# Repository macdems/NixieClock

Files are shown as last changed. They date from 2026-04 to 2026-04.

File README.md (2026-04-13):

| Supported Targets | ESP32 | ESP32-C2 | ESP32-C3 | ESP32-C5 | ESP32-C6 | ESP32-C61 | ESP32-H2 | ESP32-H21 | ESP32-H4 | ESP32-P4 | ESP32-S2 | ESP32-S3 | Linux |
| --- | ----- | --- | --- | --- | --- | --- | --- | --- | --- | --- | --- | --- | ----- |

# Hello World Example

Starts a FreeRTOS task to print "Hello World".

(See the README.md file in the upper level 'examples' directory for more information about examples.)

## How to use example

Follow detailed instructions provided specifically for this example.

Select the instructions depending on Espressif chip installed on your development board:

- [ESP32 Getting Started Guide](https://docs.espressif.com/projects/esp-idf/en/stable/get-started/index.html)
- [ESP32-S2 Getting Started Guide](https://docs.espressif.com/projects/esp-idf/en/latest/esp32s2/get-started/index.html)

## Example folder contents

The project **hello_world** contains one source file in C language [hello_world_main.c](main/hello_world_main.c). The file is located in folder [main](main).

ESP-IDF projects are built using CMake. The project build configuration is contained in `CMakeLists.txt` files that provide set of directives and instructions describing the project's source files and targets (executable, library, or both).

Below is short explanation of remaining files in the project folder.

```
├── CMakeLists.txt
├── pytest_hello_world.py      Python script used for automated testing
├── main
│   ├── CMakeLists.txt
│   └── hello_world_main.c
└── README.md                  This is the file you are currently reading
```

For more information on structure and contents of ESP-IDF projects, please refer to Section [Build System](https://docs.espressif.com/projects/esp-idf/en/latest/esp32/api-guides/build-system.html) of the ESP-IDF Programming Guide.

## Troubleshooting

* Program upload failure

    * Hardware connection is not correct: run `idf.py -p PORT monitor`, and reboot your board to see if there are any output logs.
    * The baud rate for downloading is too high: lower your baud rate in the `menuconfig` menu, and try again.

## Technical support and feedback

Please use the following feedback channels:

* For technical queries, go to the [esp32.com](https://esp32.com/) forum
* For a feature request or bug report, create a [GitHub issue](https://github.com/espressif/esp-idf/issues)

We will get back to you as soon as possible.

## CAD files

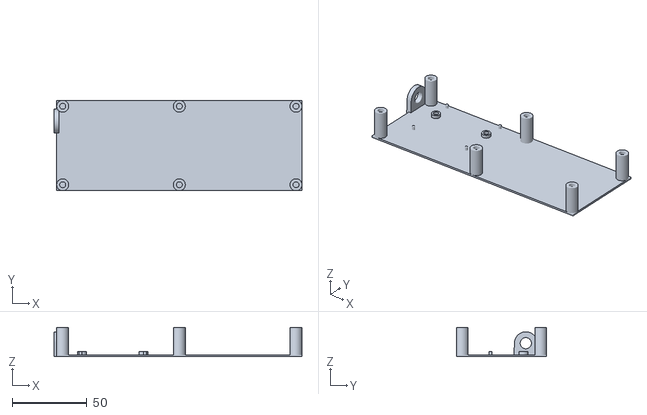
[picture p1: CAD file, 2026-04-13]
NixieClock-Base.stl
165.8 x 60.5 x 19.6

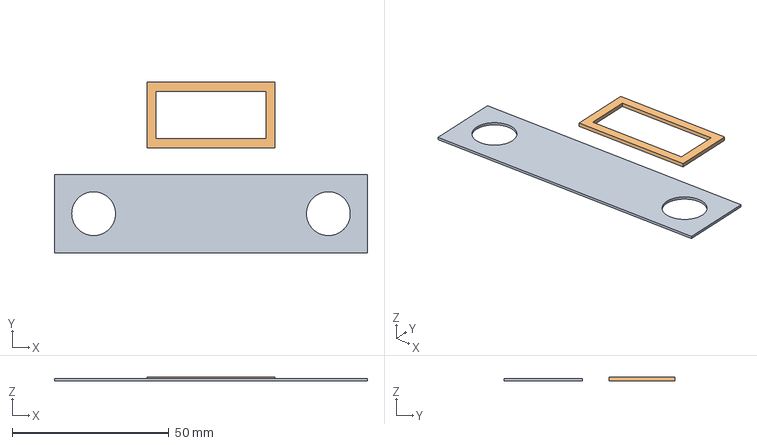
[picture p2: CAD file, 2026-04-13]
Stencil.FCStd
100.0 x 54.5 x 1.20 mm
Pipe
Plate

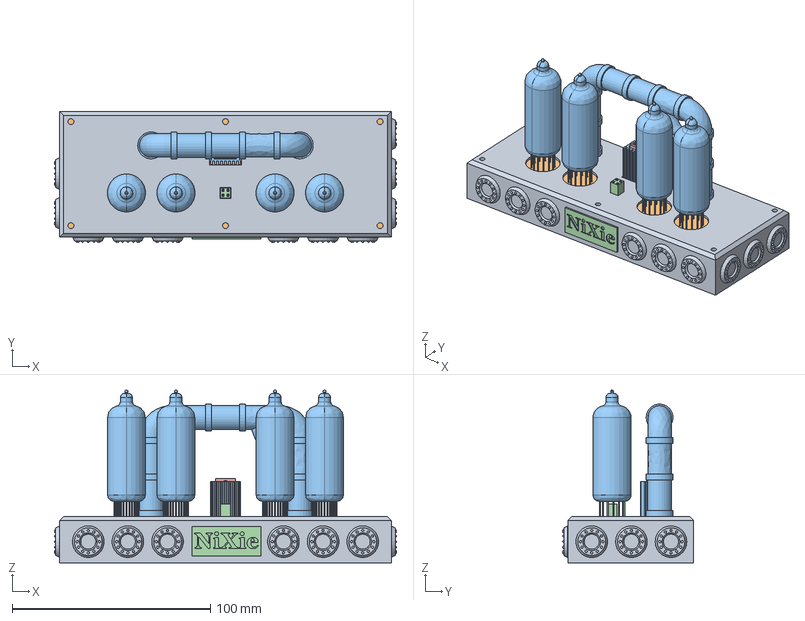
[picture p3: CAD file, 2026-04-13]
NixieClock.FCStd
172.6 x 66.0 x 87.3 mm
Pcb_86ba
HS1_Body_0fe1d42652f7
N5_PinSocket_2x02_P2.54mm_Vertical_931e53dfafea
U8_TO_220_5_Pentawatt_Multiwatt_5_Vertical_StaggeredType1_a8e8bdc4ef04
C2_CP_Radial_D50mm_P250mm_e134c9ee7a58 x 2
U4_DIP-16_W7.62mm_a7dd0eecdeba x 7
R2_R_1206_3216Metric_15a842b50147 x 6
Q2_SOT-23_20dbbeb1f2bc x 9
D6_D_SMA_a3922ec9fb80 x 3
NX-SZP-IN14-v002 x 4
NX-SZP-IN14-v003 x 4
NX-SZP-IN14-v004 x 4
NX-SZP-IN14-v005 x 4
NX-SZP-IN14-v006 x 4
NX-SZP-IN14-v007 x 4
NX-SZP-IN14-v008 x 4
NX-SZP-IN14-v009 x 4
NX-SZP-IN14-v010 x 4
NX-SZP-IN14-v011 x 4
NX-SZP-IN14-v012 x 4
NX-SZP-IN14-v013 x 4
NX-SZP-IN14-v014 x 4
NX-SZP-IN14-v015 x 4
NX-SZP-IN14-v016 x 4
NX-SZP-IN14-v017 x 4
NX-SZP-IN14-v018 x 4
NX-SZP-IN14-v019 x 4
NX-SZP-IN14-v020 x 4
NX-SZP-IN14-v021 x 4
NX-SZP-IN14-v022 x 4
NX-SZP-IN14-v023 x 4
NX-SZP-IN14-v024 x 4
NX-SZP-IN14-v025 x 4
NX-SZP-IN14-v026 x 4
NX-SZP-IN14-v027 x 4
NX-SZP-IN14-v028 x 4
NX-SZP-IN14-v029 x 4
NX-SZP-IN14-v030 x 4
NX-SZP-IN14-v031 x 4
NX-SZP-IN14-v032 x 4
NX-SZP-IN14-v033 x 4
NX-SZP-IN14-v034 x 4
NX-SZP-IN14-v035 x 4
NX-SZP-IN14-v036 x 4
NX-SZP-IN14-v037 x 4
NX-SZP-IN14-v038 x 4
NX-SZP-IN14-v039 x 4
NX-SZP-IN14-v040 x 4
NX-SZP-IN14-v041 x 4
NX-SZP-IN14-v042 x 4
NX-SZP-IN14-v043 x 4
NX-SZP-IN14-v044 x 4
NX-SZP-IN14-v045 x 4
NX-SZP-IN14-v046 x 4
NX-SZP-IN14-v047 x 4
NX-SZP-IN14-v048 x 4
Base
Pipe
Plate

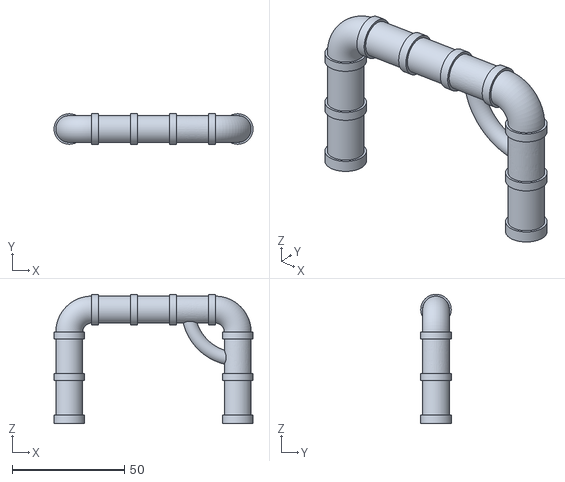
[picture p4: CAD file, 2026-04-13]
NixieClock-Pipe.stl
88.6 x 13.6 x 57.6

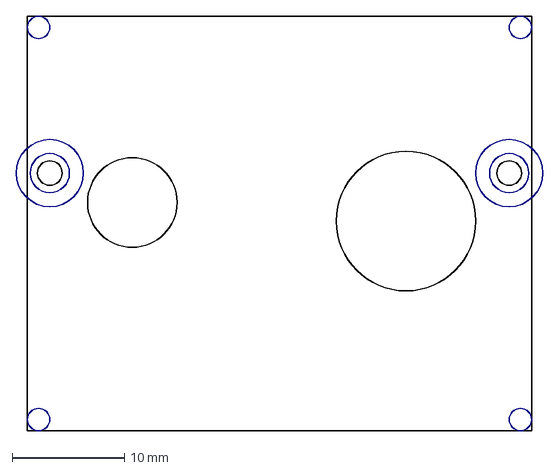
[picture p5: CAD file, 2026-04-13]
power-supply.dxf
47.0 x 37.0 mm

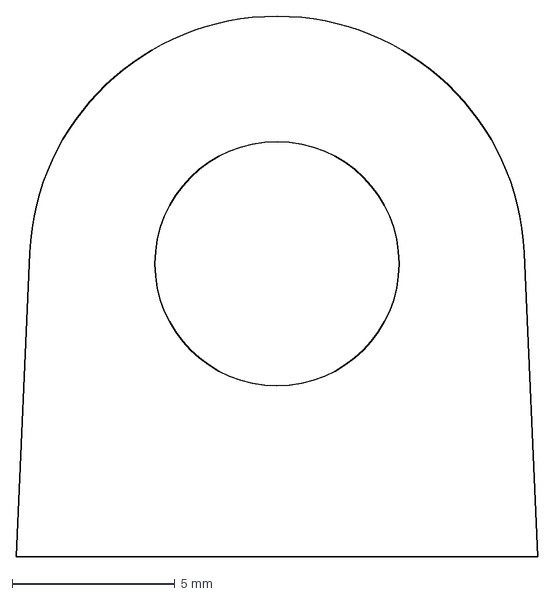
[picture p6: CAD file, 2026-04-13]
socket.dxf
16.0 x 16.6 mm

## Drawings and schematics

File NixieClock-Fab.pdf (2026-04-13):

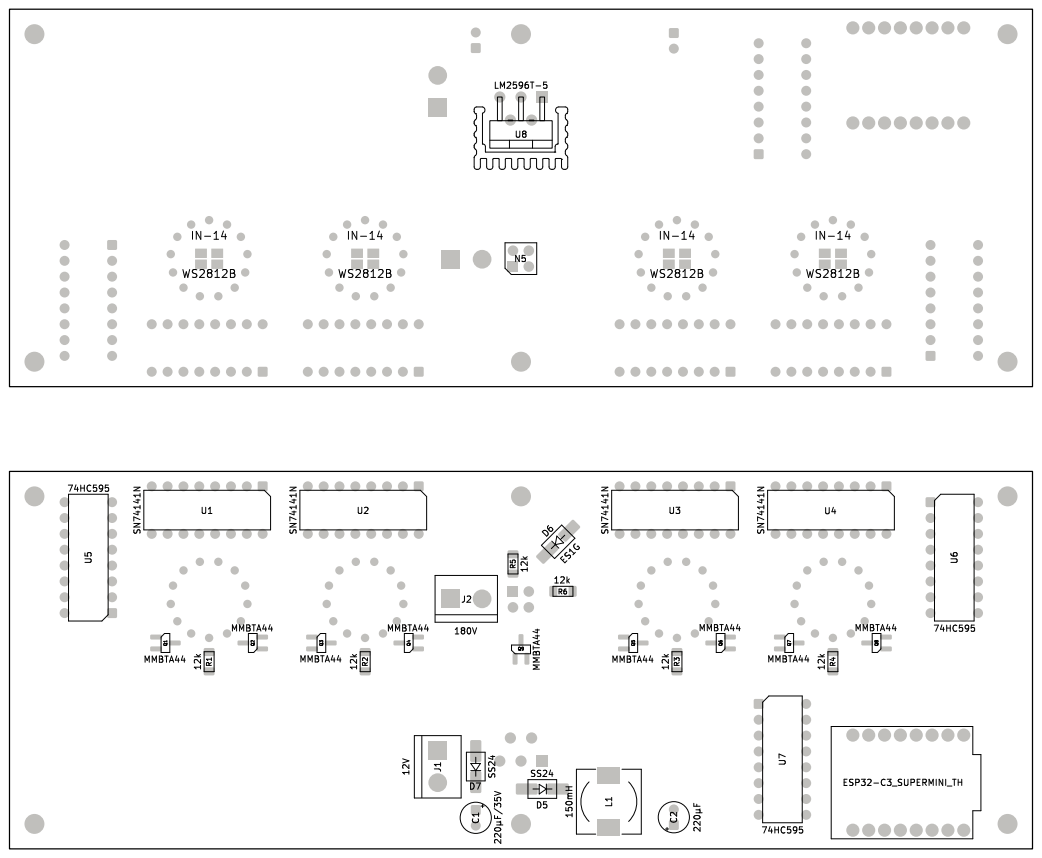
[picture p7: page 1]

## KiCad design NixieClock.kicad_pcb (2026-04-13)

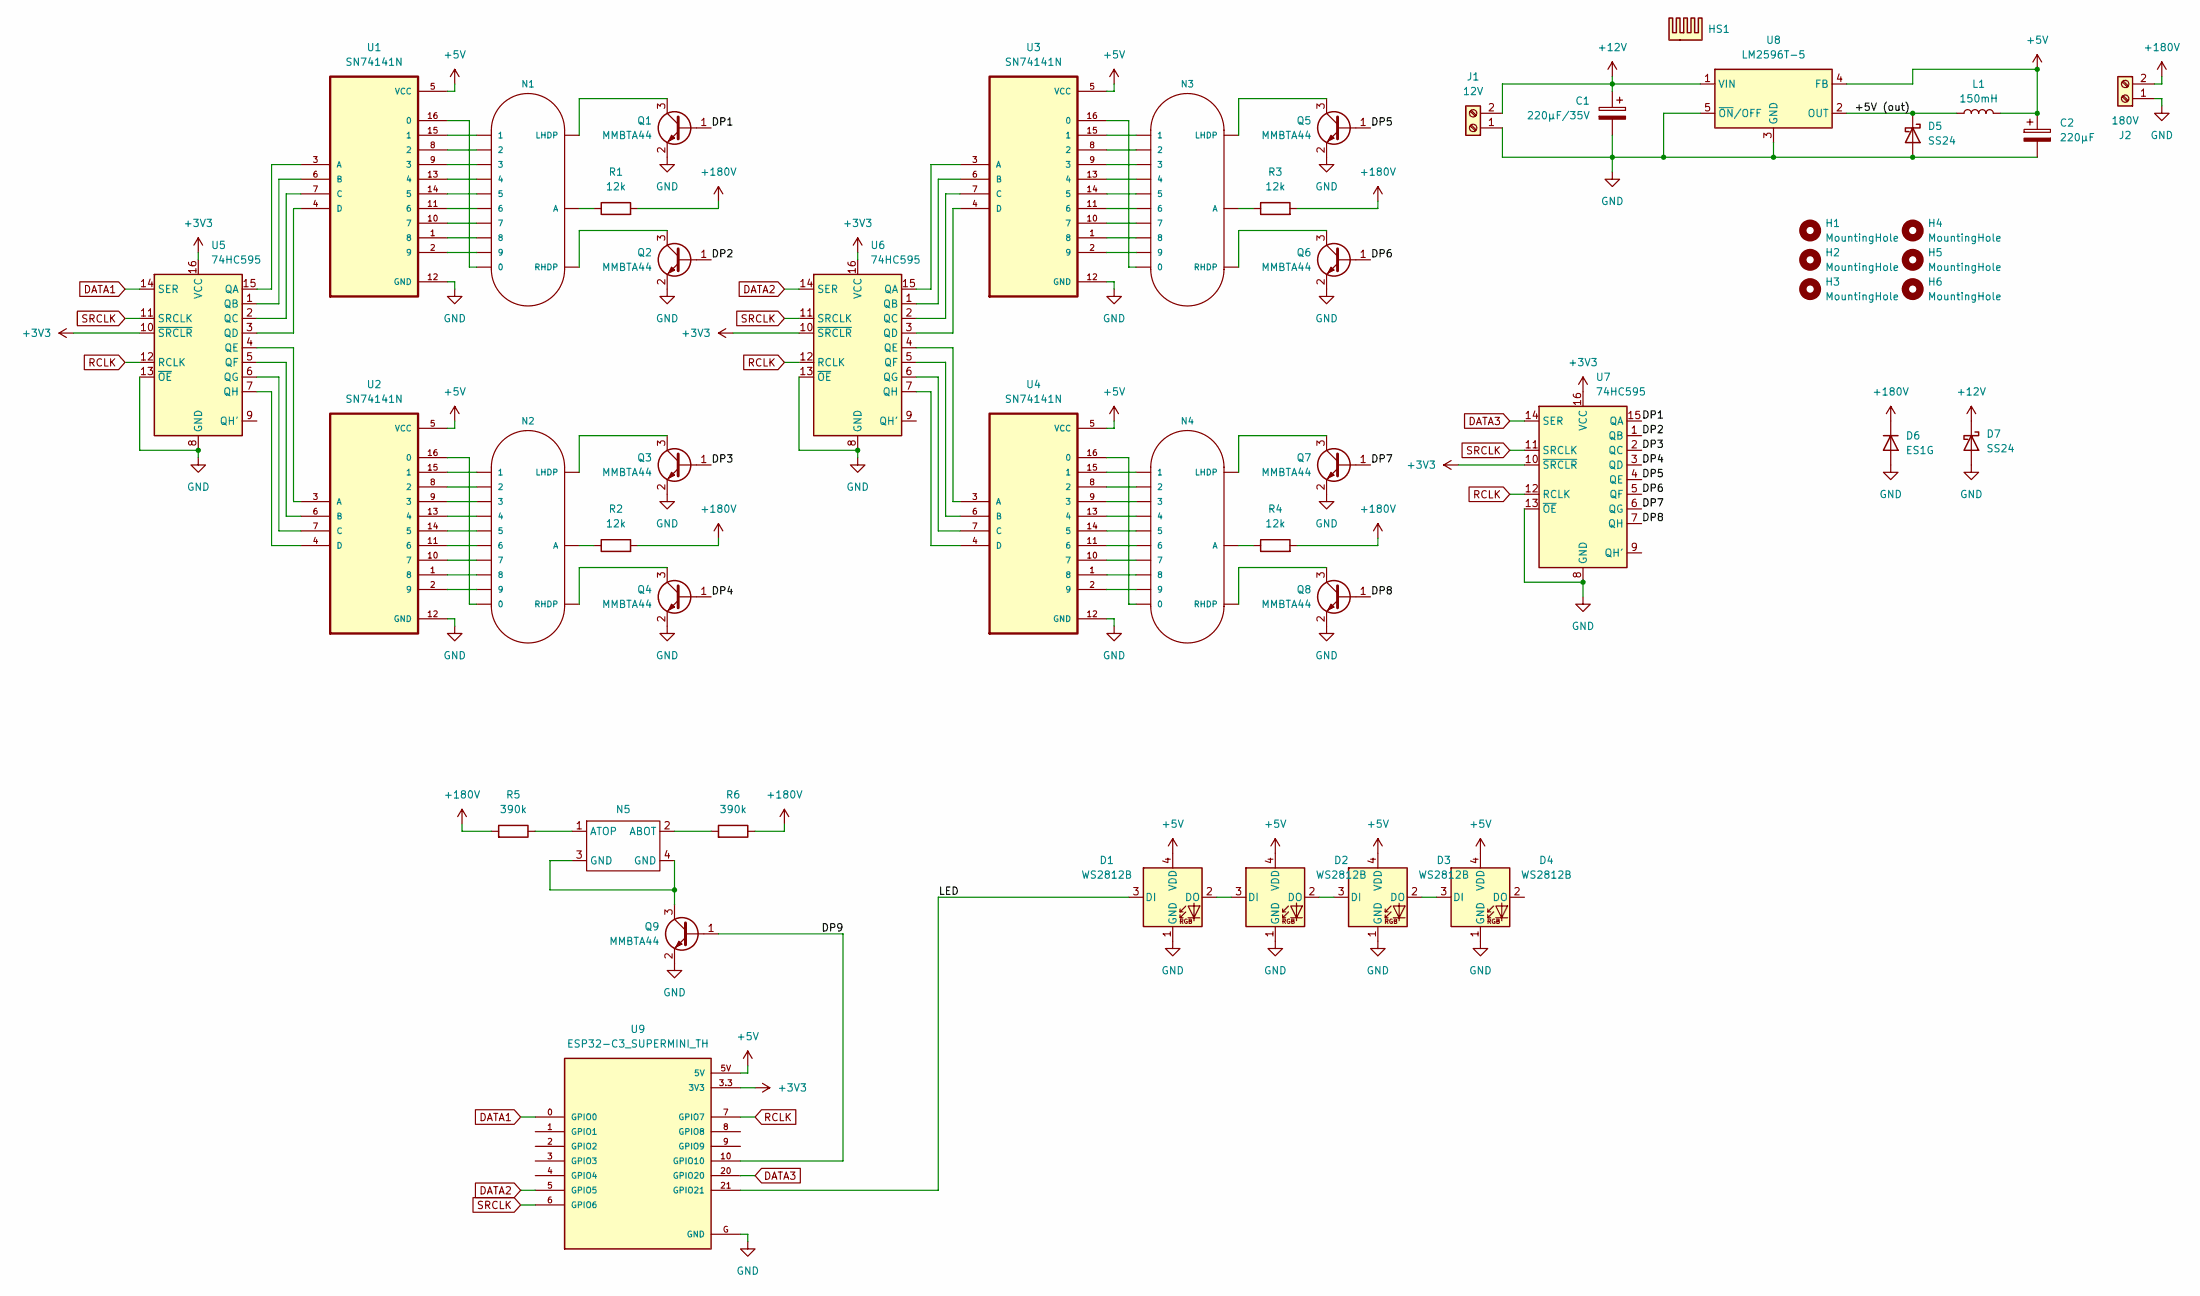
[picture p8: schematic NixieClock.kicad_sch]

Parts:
C1: 220µF/35V; CP_Radial_D5.0mm_P2.50mm
C2: 220µF; CP_Radial_D5.0mm_P2.50mm
D1, D2, D3, D4: WS2812B; LED-SMD_4P-L3.2-W2.7-TL-WS2812B-1209
D5, D7: SS24; D_SMA_Handsoldering
D6: ES1G; D_SMA_Handsoldering
H1, H2, H3, H4, H5, H6: MountingHole; MountingHole_3.2mm_M3
HS1: Heatsink; Heatsink_T8WC_TO-220
J1: 12V; TerminalBlock_bornier-2_P5.08mm
J2: 180V; TerminalBlock_bornier-2_P5.08mm
L1: 150mH; L_10.4x10.4_H4.8
N1, N2, N3, N4: IN-14
N5: PinSocket_2x02_P2.54mm_Vertical
Q1, Q2, Q3, Q4, Q5, Q6, Q7, Q8, Q9: MMBTA44; SOT-23_Handsoldering
R1, R2, R3, R4: 12k; R_1206_3216Metric_Pad1.30x1.75mm_HandSolder
R5, R6: 390k; R_1206_3216Metric_Pad1.30x1.75mm_HandSolder
U1, U2, U3, U4: SN74141N; DIP-16_W7.62mm
U5, U6, U7: 74HC595; DIP-16_W7.62mm
U8: LM2596T-5; TO-220-5_P3.4x3.7mm_StaggerOdd_Lead3.8mm_Vertical
U9: ESP32-C3_SUPERMINI_TH; MODULE_ESP32-C3_SUPERMINI_TH

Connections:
+3V3: U5.10 (~SRCLR), U5.16 (VCC), U6.10 (~SRCLR), U6.16 (VCC), U7.10 (~SRCLR), U7.16 (VCC), U9.3.3 (3V3)
+5V: C2.1, D1.4 (VDD), D2.4 (VDD), D3.4 (VDD), D4.4 (VDD), L1.2, U1.5 (VCC), U2.5 (VCC), U3.5 (VCC), U4.5 (VCC), U8.4 (FB), U9.5V
+12V: C1.1, D7.1 (K), J1.2, U8.1 (VIN)
+180V: D6.1 (K), J2.2, R1.2, R2.2, R3.2, R4.2, R5.2, R6.1
/+5V (out): D5.1 (K), L1.1, U8.2 (OUT)
/DP1: Q1.1 (B), U7.15 (QA)
/DP2: Q2.1 (B), U7.1 (QB)
/DP3: Q3.1 (B), U7.2 (QC)
/DP4: Q4.1 (B), U7.3 (QD)
/DP5: Q5.1 (B), U7.4 (QE)
/DP6: Q6.1 (B), U7.5 (QF)
/DP7: Q7.1 (B), U7.6 (QG)
/DP8: Q8.1 (B), U7.7 (QH)
/DP9: Q9.1 (B), U9.10 (GPIO10)
/LED: D1.3 (DI), U9.21 (GPIO21)
DATA1: U5.14 (SER), U9.0 (GPIO0)
DATA2: U6.14 (SER), U9.5 (GPIO5)
DATA3: U7.14 (SER), U9.20 (GPIO20)
GND: C1.2, C2.2, D1.1 (GND), D2.1 (GND), D3.1 (GND), D4.1 (GND), D5.2 (A), D6.2 (A), D7.2 (A), J1.1, J2.1, Q1.2 (E), Q2.2 (E), Q3.2 (E), Q4.2 (E), Q5.2 (E), Q6.2 (E), Q7.2 (E), Q8.2 (E), Q9.2 (E), U1.12 (GND), U2.12 (GND), U3.12 (GND), U4.12 (GND), U5.8 (GND), U5.13 (~OE), U6.8 (GND), U6.13 (~OE), U7.8 (GND), U7.13 (~OE), U8.3 (GND), U8.5 (~ON/OFF), U9.G (GND)
unnamed: D1.2 (DO), D2.3 (DI)
unnamed: D2.2 (DO), D3.3 (DI)
unnamed: D3.2 (DO), D4.3 (DI)
unnamed: N1.A, R1.1
unnamed: N2.A, R2.1
unnamed: N3.A, R3.1
unnamed: N4.A, R4.1
unnamed: N5.2 (ABOT), R6.2
unnamed: N5.1 (ATOP), R5.1
unnamed: N1.LHDP, Q1.3 (C)
unnamed: N1.RHDP, Q2.3 (C)
unnamed: N2.LHDP, Q3.3 (C)
unnamed: N2.RHDP, Q4.3 (C)
unnamed: N3.LHDP, Q5.3 (C)
unnamed: N3.RHDP, Q6.3 (C)
unnamed: N4.LHDP, Q7.3 (C)
unnamed: N4.RHDP, Q8.3 (C)
unnamed: N5.3 (GND), N5.4 (GND), Q9.3 (C)
unnamed: N1.0, U1.16 (0)
unnamed: N1.1, U1.15 (1)
unnamed: N1.2, U1.8 (2)
unnamed: N1.3, U1.9 (3)
unnamed: N1.4, U1.13 (4)
unnamed: N1.5, U1.14 (5)
unnamed: N1.6, U1.11 (6)
unnamed: N1.7, U1.10 (7)
unnamed: N1.8, U1.1 (8)
unnamed: N1.9, U1.2 (9)
unnamed: U1.3 (A), U5.15 (QA)
unnamed: U1.6 (B), U5.1 (QB)
unnamed: U1.7 (C), U5.2 (QC)
unnamed: U1.4 (D), U5.3 (QD)
unnamed: N2.0, U2.16 (0)
unnamed: N2.1, U2.15 (1)
unnamed: N2.2, U2.8 (2)
unnamed: N2.3, U2.9 (3)
unnamed: N2.4, U2.13 (4)
unnamed: N2.5, U2.14 (5)
unnamed: N2.6, U2.11 (6)
unnamed: N2.7, U2.10 (7)
unnamed: N2.8, U2.1 (8)
unnamed: N2.9, U2.2 (9)
unnamed: U2.3 (A), U5.4 (QE)
unnamed: U2.6 (B), U5.5 (QF)
unnamed: U2.7 (C), U5.6 (QG)
unnamed: U2.4 (D), U5.7 (QH)
unnamed: N3.0, U3.16 (0)
unnamed: N3.1, U3.15 (1)
unnamed: N3.2, U3.8 (2)
unnamed: N3.3, U3.9 (3)
unnamed: N3.4, U3.13 (4)
unnamed: N3.5, U3.14 (5)
unnamed: N3.6, U3.11 (6)
unnamed: N3.7, U3.10 (7)
unnamed: N3.8, U3.1 (8)
unnamed: N3.9, U3.2 (9)
unnamed: U3.3 (A), U6.15 (QA)
unnamed: U3.6 (B), U6.1 (QB)
unnamed: U3.7 (C), U6.2 (QC)
unnamed: U3.4 (D), U6.3 (QD)
unnamed: N4.0, U4.16 (0)
unnamed: N4.1, U4.15 (1)
unnamed: N4.2, U4.8 (2)
unnamed: N4.3, U4.9 (3)
unnamed: N4.4, U4.13 (4)
unnamed: N4.5, U4.14 (5)
unnamed: N4.6, U4.11 (6)
unnamed: N4.7, U4.10 (7)
unnamed: N4.8, U4.1 (8)
unnamed: N4.9, U4.2 (9)
unnamed: U4.3 (A), U6.4 (QE)
unnamed: U4.6 (B), U6.5 (QF)
unnamed: U4.7 (C), U6.6 (QG)
unnamed: U4.4 (D), U6.7 (QH)
RCLK: U5.12 (RCLK), U6.12 (RCLK), U7.12 (RCLK), U9.7 (GPIO7)
SRCLK: U5.11 (SRCLK), U6.11 (SRCLK), U7.11 (SRCLK), U9.6 (GPIO6)

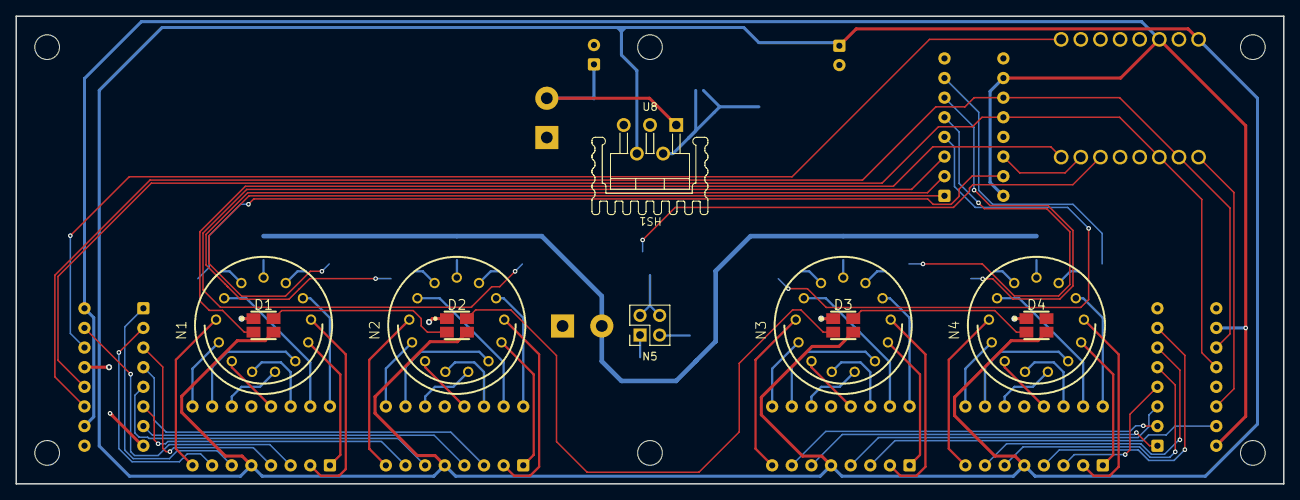
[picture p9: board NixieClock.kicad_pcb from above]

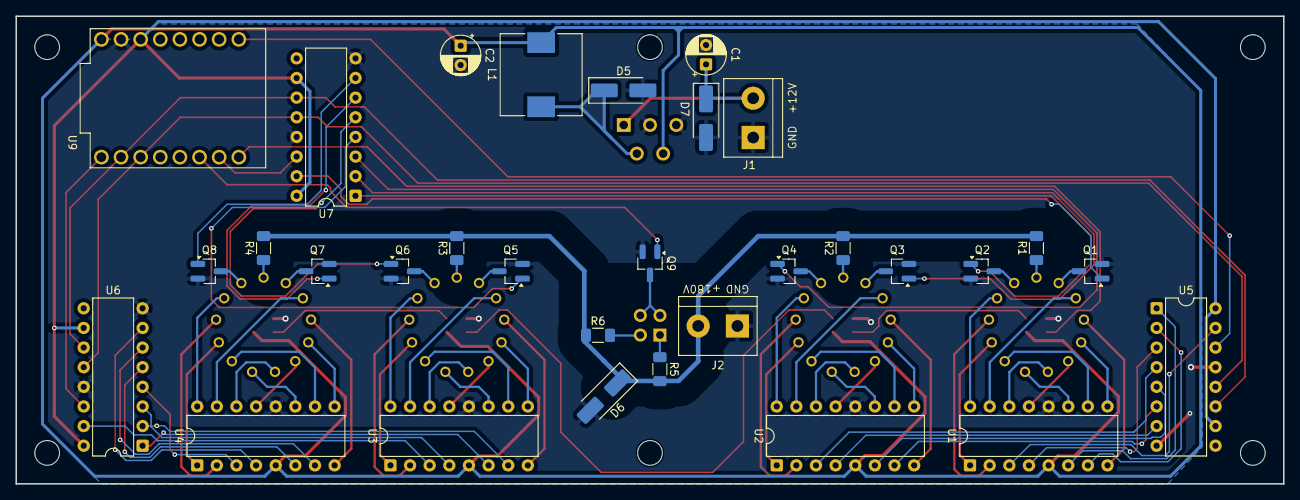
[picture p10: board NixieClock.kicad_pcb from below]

Board: 2 copper layers, 164.0 x 60.5 mm, 48 parts (31 on the bottom side), 95 nets.

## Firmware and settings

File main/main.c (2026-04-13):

/*
 * SPDX-FileCopyrightText: 2010-2022 Espressif Systems (Shanghai) CO LTD
 *
 * SPDX-License-Identifier: CC0-1.0
 */

#include <inttypes.h>
#include <stdio.h>
#include <string.h>

#include <esp_app_desc.h>
#include <esp_event.h>
#include <esp_log.h>
#include <esp_system.h>
#include <esp_wifi.h>
#include <freertos/FreeRTOS.h>
#include <freertos/task.h>
#include <nvs_flash.h>

#include "clock.h"
#include "effects.h"
#include "gpio.h"
#include "leds.h"
#include "log.h"
#include "mqtt.h"
#include "nixies.h"
#include "nvs.h"
#include "ota.h"

// static const char* const TAG = "main";

#define LED_PIN GPIO_NUM_8

static bool primary_wifi = true;

static void connect_wifi() {
    wifi_config_t wifi_config = {
        .sta =
            {
                .threshold.authmode = WIFI_AUTH_WPA2_PSK,
            },
    };

    if (!primary_wifi) {
        strncpy((char*)wifi_config.sta.ssid, CONFIG_WIFI_SSID, sizeof(wifi_config.sta.ssid));
        strncpy((char*)wifi_config.sta.password, CONFIG_WIFI_PASSWORD, sizeof(wifi_config.sta.password));
    } else {
        strncpy((char*)wifi_config.sta.ssid, CONFIG_WIFI_SSID_2, sizeof(wifi_config.sta.ssid));
        strncpy((char*)wifi_config.sta.password, CONFIG_WIFI_PASSWORD_2, sizeof(wifi_config.sta.password));
    }
    ESP_ERROR_CHECK(esp_wifi_set_config(WIFI_IF_STA, &wifi_config));
    ESP_ERROR_CHECK(esp_wifi_connect());
}

static void on_wifi_event(void* arg, esp_event_base_t event_base, int32_t event_id, void* event_data) {
    switch (event_id) {
        case WIFI_EVENT_STA_START: connect_wifi(); return;
        case WIFI_EVENT_STA_CONNECTED:
            progress_boot_dots("WiFi connected");  // (4)
            return;
        case WIFI_EVENT_STA_DISCONNECTED:
            primary_wifi = !primary_wifi;
            connect_wifi();
            return;
        default: return;
    }
}

static void on_ip_event(void* arg, esp_event_base_t event_base, int32_t event_id, void* event_data) {
    switch (event_id) {
        case IP_EVENT_STA_GOT_IP:
            // Start network services
            progress_boot_dots("Got IP");  // (5)
            init_mqtt_client();
            progress_boot_dots("MQTT client initialized");  // (6)
            init_clock();
            gpio_set_level(LED_PIN, 1);
            return;
        default: return;
    }
    // ip_event_got_ip_t* event = (ip_event_got_ip_t*)event_data;
    // ESP_LOGI(TAG, "Got IP: " IPSTR, IP2STR(&event->ip_info.ip));
}

static esp_err_t init_wifi() {
    ESP_ERROR_CHECK(esp_netif_init());
    esp_netif_t* sta = esp_netif_create_default_wifi_sta();
    assert(sta);

    wifi_init_config_t cfg = WIFI_INIT_CONFIG_DEFAULT();
    ESP_ERROR_CHECK(esp_wifi_init(&cfg));
    esp_event_handler_instance_register(IP_EVENT, IP_EVENT_STA_GOT_IP, on_ip_event, NULL, NULL);
    esp_event_handler_instance_register(WIFI_EVENT, ESP_EVENT_ANY_ID, on_wifi_event, NULL, NULL);
    ESP_ERROR_CHECK(esp_wifi_set_mode(WIFI_MODE_STA));
    ESP_ERROR_CHECK(esp_wifi_start());
    return ESP_OK;
}

void app_main() {
    // Initialize logging
    init_logging();

    // Configure on-board LED GPIO and turn it on (will turn off after successful WiFi connection)
    configure_gpio(HOUR_PIN, 0);
    configure_gpio(MINUTE_PIN, 0);
    configure_gpio(DOTS_PIN, 0);
    configure_gpio(COLON_PIN, 0);
    configure_gpio(SRCLK_PIN, 0);
    configure_gpio(RCLK_PIN, 0);
    configure_gpio(LED_PIN, 0);

    // Turn off any display
    display_digits(-1, -1, -1, -1);
    progress_boot_dots("GPIO initialized");  // (1)

    // Initialize NVS
    esp_err_t err = nvs_flash_init();
    if (err == ESP_ERR_NVS_NO_FREE_PAGES) {
        // OTA app partition table has a smaller NVS partition size than the non-OTA
        // partition table. This size mismatch may cause NVS initialization to fail.
        // If this happens, we erase NVS partition and initialize NVS again.
        ESP_ERROR_CHECK(nvs_flash_erase());
        err = nvs_flash_init();
    }
    ESP_ERROR_CHECK(err);

    init_nvs();
    init_leds();

    ESP_ERROR_CHECK(esp_event_loop_create_default());
    ESP_ERROR_CHECK(init_wifi());
    progress_boot_dots("WiFi initialized");  // (2)

    start_digits_effect(DIGITS_EFFECT_BOOT);
    progress_boot_dots("After digits scan");  // (3)

#if defined(CONFIG_BOOTLOADER_APP_ROLLBACK_ENABLE)
    ota_cancel_rollback();
#endif
}

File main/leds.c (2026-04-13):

#include <esp_err.h>
#include <esp_log.h>
#include <nvs_flash.h>

#include <led_strip.h>

#include "leds.h"
#include "mqtt.h"
#include "nvs.h"

#define LED_STRIP_GPIO_PIN 21

_Atomic bool leds_on = true;
_Atomic uint16_t leds_hue = 240;
_Atomic uint8_t leds_saturation = 255;
_Atomic uint8_t leds_value = 255;

static const char* const TAG = "leds";

static led_strip_handle_t led_strip;

void init_leds() {
    led_strip_config_t strip_config = {
        .strip_gpio_num = LED_STRIP_GPIO_PIN,                         // The GPIO that connected to the LED strip's data line
        .max_leds = 4,                                                // The number of LEDs in the strip,
        .led_model = LED_MODEL_WS2812,                                // LED strip model
        .color_component_format = LED_STRIP_COLOR_COMPONENT_FMT_GRB,  // set the color order of the strip: GRB
        .flags = {.invert_out = false}                                // don't invert the output signal
    };

    // LED strip backend configuration: SPI
    led_strip_spi_config_t spi_config = {
        .clk_src = SPI_CLK_SRC_DEFAULT,  // different clock source can lead to different power consumption
        .spi_bus = SPI2_HOST,            // SPI bus ID
        .flags = {.with_dma = true}      // Using DMA can improve performance and help drive more LEDs
    };

    // LED Strip object handle
    ESP_ERROR_CHECK(led_strip_new_spi_device(&strip_config, &spi_config, &led_strip));
    ESP_LOGI(TAG, "Created LED strip object with SPI backend");

    update_leds();
}

void update_leds() {
    if (led_strip == NULL) {
        ESP_LOGW(TAG, "LED strip not initialized");
        return;
    }

    if (leds_on) {
        // Set all pixels to the specified HSV color
        for (uint32_t i = 0; i < 4; i++) {
            ESP_ERROR_CHECK(led_strip_set_pixel_hsv(led_strip, i, leds_hue, leds_saturation, leds_value));
        }
        mqtt_client_publish("leds/state", "ON", 1);
        ESP_LOGI(TAG, "LEDs updated: H=%d, S=%d, V=%d", leds_hue, leds_saturation, leds_value);
    } else {
        // Turn off all LEDs
        for (uint32_t i = 0; i < 4; i++) {
            ESP_ERROR_CHECK(led_strip_set_pixel(led_strip, i, 0, 0, 0));
        }
        mqtt_client_publish("leds/state", "OFF", 1);
        ESP_LOGI(TAG, "LEDs turned off");
    }

    // Refresh the strip to apply changes
    ESP_ERROR_CHECK(led_strip_refresh(led_strip));

    save_state_to_nvs();
}

void publish_initial_leds_state() {
    const char* state = leds_on ? "ON" : "OFF";
    mqtt_client_publish("leds/state", state, 1);

    char hs_state[32];
    float s_percent = leds_saturation * 100.0f / 255.0f;
    snprintf(hs_state, sizeof(hs_state), "%d.000,%.3f", leds_hue, s_percent);
    mqtt_client_publish("leds/hs/state", hs_state, 1);
}

bool handle_led_command(const char* topic, int topic_len, const char* data, int data_len) {
    if (strncmp(topic, "leds/set", topic_len) == 0) {
        // Expect "ON" or "OFF"
        if (data_len >= 2 && !strncmp(data, "ON", 2)) {
            leds_on = true;
        } else {
            leds_on = false;
        }
        update_leds();
        // Echo state back
        const char* state = leds_on ? "ON" : "OFF";
        mqtt_client_publish("leds/state", state, 1);
        ESP_LOGI(TAG, "'Leds' set -> %s", state);
        return true;
    }

    if (strncmp(topic, "leds/brightness/set", topic_len) == 0) {
        const char value[16];
        copy_str_to_buffer(data, data_len, (char*)value, sizeof(value));
        int brightness = atoi(value);
        // Expect brightness value 0-255
        if (brightness < 0) brightness = 0; else if (brightness > 255) brightness = 255;
        leds_value = (uint8_t)brightness;
        update_leds();
        // Echo state back
        char state[16];
        snprintf(state, sizeof(state), "%d", brightness);
        mqtt_client_publish("leds/brightness/state", state, 1);
        ESP_LOGI(TAG, "'Leds' brightness set -> %d", brightness);
        return true;
    }

    if (strncmp(topic, "leds/hs/set", topic_len) == 0) {
        // Expect "H,S" where H=0-360., S=0-100.
        const char value[128];
        copy_str_to_buffer(data, data_len, (char*)value, sizeof(value));
        float h = 0.0f, s = 0.0f;
        int parsed = sscanf(value, "%f,%f", &h, &s);
        if (parsed == 2) {
            if (h < 0.0f || h >= 360.0f) h = 0.0f;
            if (s < 0.0f) s = 0.0f; else if (s > 100.0f) s = 100.0f;
            leds_hue = (uint16_t)h;
            leds_saturation = (uint8_t)(s * 255.0f / 100.0f);
            update_leds();
            // Echo state back
            char state[32];
            snprintf(state, sizeof(state), "%.1f,%.1f", h, s);
            mqtt_client_publish("leds/hs/state", state, 1);
            ESP_LOGI(TAG, "'Leds' HS set -> %.1f, %.1f  [%d, %d]", h, s, leds_hue, leds_saturation);
            return true;
        }
    }

    return false;
}

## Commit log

2026-04-13 Initial appication framework
    [NixieClock-Base.stl, NixieClock-Pipe.stl, NixieClock.FCStd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]
2026-04-28 Add BOM and manufacturing instructions to README
2026-04-28 Fix MQTT discovery and RSSI timer
